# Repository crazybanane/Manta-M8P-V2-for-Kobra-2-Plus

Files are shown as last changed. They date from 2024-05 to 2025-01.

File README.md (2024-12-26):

THIS REPO IS UNDER CONSTRUCTION!!!!

UPDATE 26.12.2024

Hello,

here you can find the Printer.cfg for an Kobra 2 Plus in combination with an Manta M8P v2.0

At the moment there is only a tested Version that works for me!
Test at your own risk!!!
Updates follows.

Also you can get Print files to Print for your own New Housing for the Hardware, you find them in "Case Print Files". Please lookup with your connections and configuration. This is an early Version that is not 100% correct!

PLS advice that you can change PINs to your own likeness but then you have to edit the CFG!

| Part | Pinout Label | Manta M8P v2.0 | Pin / Pin Assignment |
|----|----|----|----|
| Probe / ABL Sensor | E-CON: LEVEL | Probe PD13 | If you use BlTouch: (PD13/Sensor) \[PD12/Servo) |
| Acceleration Sensor Printhead = X E-CON | E-CON: MOSI E-CON: MISO E-CON: SCLK E-CON: CS E-CON: 5V | SPI: SPI_MOSI SPI: SPI_MISO SPI: SPI_SCK SPI: SPI_CS SPI: 5V SPI_GND| PA7 PA6 PA5 PE10 (SPI: 5V) (SPI: GND)|
| Acceleration Sensor Bed = Y ACC-SENSOR | ACC-SENSOR: MOSI ACC-SENSOR: MISO ACC-SENSOR: SCLK ACC-SENSOR: CS ACC-SENSOR: 5V ACC-SENSOR: GND | SPI: SPI_MOSI SPI: SPI_MISO SPI: SPI_SCK RGB: PD15 SPI_5V: 5V SPI_GND: SPI_GND| PA7 PA6 PA5 PD15 (Motor: 5V) (Motor → GND -) |
| Printhead's 24V main | E-CON: 24V | Motor Fan → 24V + | (Motor Fan → 24V +) |
| Printhead's GND main | E-CON: GND | Motor Fan → 24V - | (Motor Fan → 24V -) |
| Part Cooling Fan | E-CON: F0 | FAN1 | FAN0 PF7 |
| Heatsink Cooling Fan | E-CON: F1 | FAN2 | FAN1 PF9 |
| Thermistor Hotend | E-CON: T0 | TH1 | PC1 |
| Cartridge Heater | E-CON: H+ / H- (3x) | HE0+ / HE0- | HE0 PA0 |
| Thermistor Bed | T1/GND | TB1 | PC0 |
| Heater Bed | HOTBED + / - | H-BED + / - | BED OUT PF5 |
| PE / Chassis GND | E-/X-CON: CHASSIS GND | PE-Wire PSU | (PE-Wire PSU) |
| Filament Runout Sensor | X-CON: FILAMENT/GND | MT_DET1 !PF2/GND | !PF2 M3-Stop |
| X Limit Switch | X-CON: X LIMIT/GND | X !PF4/GND | !PF4 M1-Stop |
| Y Limit Switch | Y-CON: LIMIT/GND | Y !PF3/GND | !PF3 M2-Stop |
| Mainboard Cooling Fan | MB-FAN + / - | FAN2 → 24V + / - | (FAN2 PF6 → 24V + / -) |
| Z-Offset Sensor | CALIBRATION S/GND | Z+ PD13/14/GND | ^PD13/14 |
| Extruder Motor | E-CON: A1/A2/B1/B2 | E0-MOTOR: 1A/1B/2A/2B | step: PB5 / dir: PB3 / enable: !PB6 / uart: PD5 |
| X-Axis Motor | X-CON: A1/A2/B1/B2 | X-MOTOR: 1A/1B/2A/2B | step: PE6 / dir: PE5 / enable: !PC14 / uart: PC13 |

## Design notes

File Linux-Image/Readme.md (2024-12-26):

Pre-Alpha State!!!!

Hello, 

i got a booting version for CB2 with newer kernel and "latest" (25.02) Armbian Version and kernel 6.12.

I dont take care if you use this Image, its under your own risk!

First Download CB2 image https://drive.google.com/file/d/1ZcWxQnl73ZC4QlOMRiY9tBDAFCI9ZEce/view?usp=sharing
Burn Image to SD-Card
Open SD-Card on your Computer goto directory "root" and search for file "not logged in yet"

Open the file and change it to your settings that you need (Wifi/password/User etc.)
Save the file and put the Card in the Printer.

Wait about 2-3 mins to boot, you should see with a programm of your choice that there will be an IP address to where you can connect via SSH.

First you have to log in with root/1234

wait until terminal is refreshed then logout and login via user biqu pass biqu and now you have to manually install Klipper via Kiauh.

* **Step 1:** \
To download this script, it is necessary to have git installed. If you don't have git already installed, or if you are unsure, run the following command:
```shell
sudo apt-get update && sudo apt-get install git -y
```

* **Step 2:** \
Once git is installed, use the following command to download KIAUH into your home-directory:

* **Step 3:** \
Finally, start KIAUH by running the next command:

* **Step 4:** \
You should now find yourself in the main menu of KIAUH. You will see several actions to choose from depending
on what you want to do. To choose an action, simply type the corresponding number into the "Perform action"
prompt and confirm by hitting ENTER.

After you installed the minimal Klipper functions you have to edit serial.rules

Open MC and search for 

Edit file 

and Copy Paste following text

```shell
# do not edit this file, it will be overwritten on update

ACTION=="remove", GOTO="serial_end"
SUBSYSTEM!="tty", GOTO="serial_end"

SUBSYSTEMS=="usb", IMPORT{builtin}="usb_id", IMPORT{builtin}="hwdb --subsystem=usb"
SUBSYSTEMS=="pci", ENV{ID_BUS}=="", ENV{ID_BUS}="pci", \
  ENV{ID_VENDOR_ID}="$attr{vendor}", ENV{ID_MODEL_ID}="$attr{device}", \
  IMPORT{builtin}="hwdb --subsystem=pci"

# /dev/serial/by-path/, /dev/serial/by-id/ for USB devices
KERNEL!="ttyUSB[0-9]*|ttyACM[0-9]*", GOTO="serial_end"

SUBSYSTEMS=="usb-serial", ENV{.ID_PORT}="$attr{port_number}"

IMPORT{builtin}="path_id"
ENV{ID_PATH}=="?*", ENV{.ID_PORT}=="", SYMLINK+="serial/by-path/$env{ID_PATH}"
ENV{ID_PATH}=="?*", ENV{.ID_PORT}=="?*", SYMLINK+="serial/by-path/$env{ID_PATH}-port$env{.ID_PORT}"

IMPORT{builtin}="usb_id"
ENV{ID_SERIAL}=="", GOTO="serial_end"
SUBSYSTEMS=="usb", ENV{ID_USB_INTERFACE_NUM}="$attr{bInterfaceNumber}"
ENV{ID_USB_INTERFACE_NUM}=="", GOTO="serial_end"
ENV{.ID_PORT}=="", SYMLINK+="serial/by-id/$env{ID_BUS}-$env{ID_SERIAL}-if$env{ID_USB_INTERFACE_NUM}"
ENV{.ID_PORT}=="?*", SYMLINK+="serial/by-id/$env{ID_BUS}-$env{ID_SERIAL}-if$env{ID_USB_INTERFACE_NUM}-port$env{.ID_PORT}"

LABEL="serial_end"

```

save file.

Now reboot CB2

In terminal type

put in editor

```shell
allow-hotplug can0
iface can0 can static
        bitrate 1000000
        up ip link set can0 txqueuelen 1024
```

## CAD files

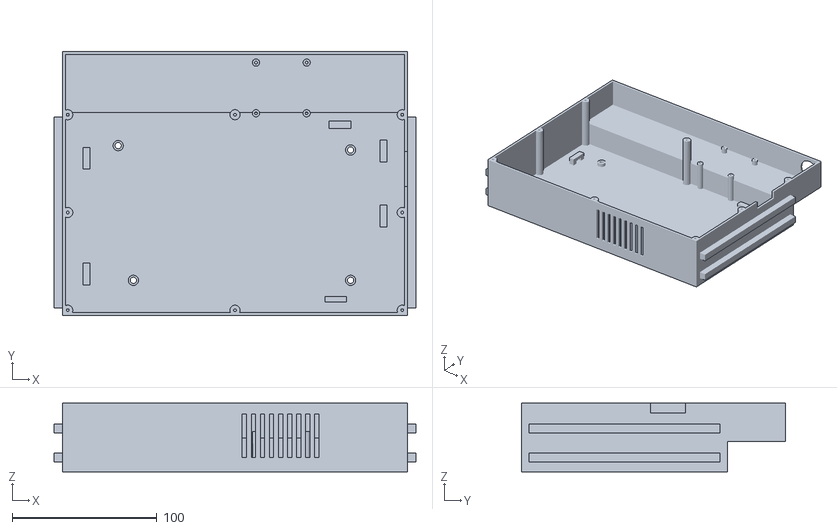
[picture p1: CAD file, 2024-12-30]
Case Print Files/Kobra 2Plus HW-Case M3.stl
250.0 x 182.0 x 47.5

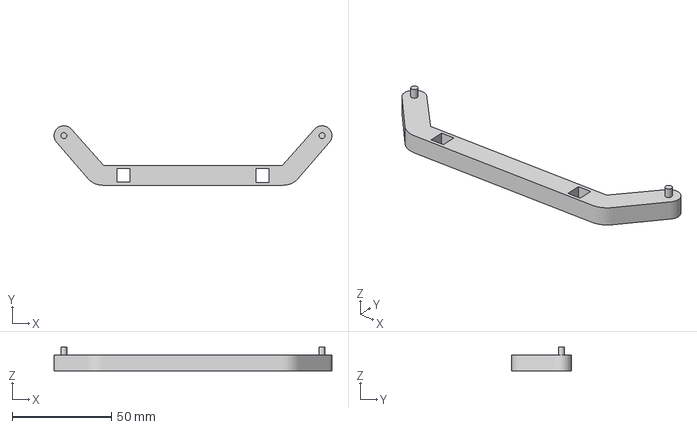
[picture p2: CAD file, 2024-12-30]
Printable Upgrades/halter rolle.3mf
140.0 x 30.0 x 12.0 mm

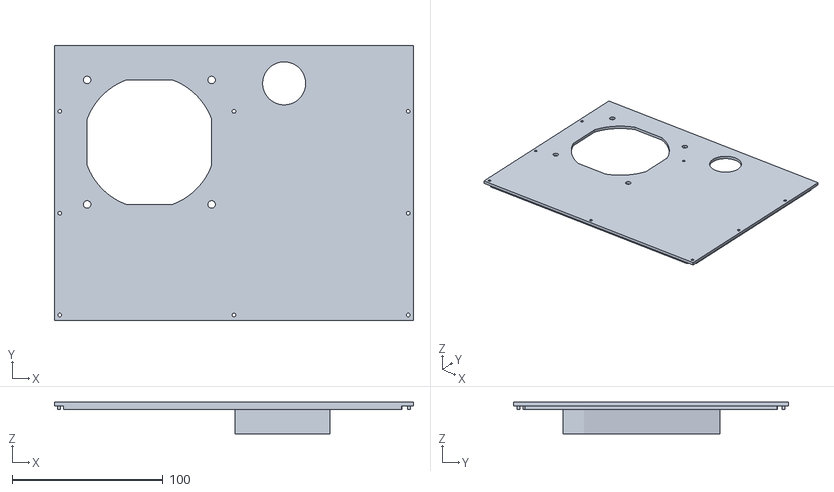
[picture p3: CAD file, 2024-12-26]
Case Print Files/Kobra 2 Plus Case HW-Lid.stl
238.0 x 182.0 x 21.2

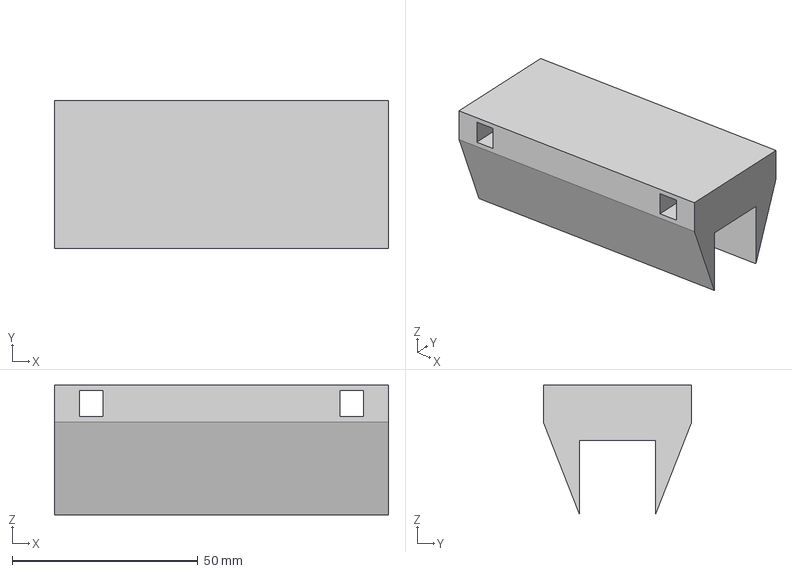
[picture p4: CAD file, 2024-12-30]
Printable Upgrades/halter rolle oben.3mf
90.0 x 40.0 x 35.0 mm

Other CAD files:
Case Print Files/Kobra 2 Plus HW-Case Melt Studs.stl

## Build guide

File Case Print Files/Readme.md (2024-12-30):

Hello here you can find an Case for Kobra 2 Plus to printyourself.
The Cases are made ONLY for Manta M8P V2 Board.
There i use 2 different FANs.
The 4020 Blower Fan is for cooling the Motor-Drivers
The 82mm Fan is for cooling CB2
You can choose between 2 Layouts

- Case with melt points to hold Board "Forever" 
- Case with holes to melt in Brass M3 nuts "Detachable" MoBo
- Lid is not tested yet !!!

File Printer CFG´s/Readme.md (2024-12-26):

Here you find the "printer.cfg"s for Kobra 2 Plus.

The Backup of the original Printer Hardware you find under K2PLUS-Orig-printer.cfg.

The Edited Version for Manta M8P V2 Board you find under K2PLUS-M8PV2-printer.cfg

When you use the CFGs dont forget to Change names to printer.cfg before you Upload to Klipper.

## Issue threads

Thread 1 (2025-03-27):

case files

dash3811, 2025-03-27:
can you proide the case files so taht we can edit them in fusion or some other software? They are too big for me to print and i need to edit them.

Closed 2025-04-21.

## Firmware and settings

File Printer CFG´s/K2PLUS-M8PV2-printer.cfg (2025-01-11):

# This file contains common pin mappings for the BIGTREETECH Manta M8P V2.0 for an Anycubic Kobra 2 Plus Printer
# To use this config, the firmware should be compiled for the
# STM32H723 with a "128KiB bootloader" "25 MHz crystal"
# and "USB (on PA11/PA12)", "CAN bus (on PD0/PD1)" or Serial (on USART1 PA10/PA9).
[include mainsail.cfg]

# Motor1
[stepper_x]
step_pin: PE6
dir_pin: PE5
enable_pin: !PC14
microsteps: 16
rotation_distance: 31.85
endstop_pin: ^!PF4
position_endstop: -8.0
position_max : 330.0
position_min : -9.0
homing_speed : 100.000000
second_homing_speed : 15.000000
homing_retract_dist : 10

# Motor2
[stepper_y]
step_pin: PE2
dir_pin: PE1
enable_pin: !PE4
microsteps: 16
rotation_distance: 31.76
endstop_pin: ^!PF3
position_endstop : -5.000000
position_max : 330.000000
position_min : -5
homing_speed : 100.000000
second_homing_speed : 15.000000
homing_retract_dist : 10


# Motor3
[stepper_z]
step_pin: PB8
dir_pin: PB7
enable_pin: !PE0
microsteps: 16
rotation_distance: 7.98
#endstop_pin: ^PF2
#position_endstop : 1.080000
endstop_pin: probe:z_virtual_endstop
position_max : 401.000000
position_min : -5
homing_speed : 32.000000
homing_retract_dist : 8
second_homing_speed : 4.000000

# Motor4
# The M8P only has 4 heater outputs which leaves an extra stepper
# This can be used for a second Z stepper, dual_carriage, extruder co-stepper,
# or other accesory such as an MMU
[extruder]
step_pin: PB4
dir_pin: PB3
enable_pin: !PB6
heater_pin: PA0 # HE0
sensor_pin: PB0 # T0
microsteps : 16
rotation_distance: 6.7
nozzle_diameter : 0.600000
filament_diameter : 1.750000
max_extrude_cross_section: 20
sensor_type : EPCOS 100K B57560G104F
#control : pid
#pid_Kp : 12.723368
#pid_Ki : 0.489360
#pid_Kd : 82.701890
min_temp : -273.15
max_temp : 275
pressure_advance : 0.033600

# Motor5
#[extruder]
#step_pin: PG13
#dir_pin: PG12
#enable_pin: !PG15
#microsteps: 16
#rotation_distance: 33.500
#nozzle_diameter: 0.4
#filament_diameter: 1.75
#heater_pin: PA0 # HE0
#sensor_pin: PB0 # T0
#sensor_type: Generic 3950
#control: pid
#pid_Kp: 22.2
#pid_Ki: 1.08
#pid_Kd: 114
#min_temp: 0
#max_temp: 250

## End-Stop 5
#[filament_switch_sensor material_0]
#switch_pin: PF0

## Motor6
#[extruder1]
#step_pin: PG9
#dir_pin: PD7
#enable_pin: !PG11 
#heater_pin: PA1 # HE1 
#sensor_pin: PC5 # T1
#...

## End-Stop 6
#[filament_switch_sensor material_1]
#switch_pin: PC15

## Motor7
#[extruder2]
#step_pin: PD4
#dir_pin: PD3
#enable_pin: !PD6
#heater_pin: PA3 # HE2
#sensor_pin: PC4 # T2
#...

## Motor8
#[extruder3]
#step_pin: PC7
#dir_pin: PC8
#enable_pin: !PD2
#heater_pin: PA5 # HE3
#sensor_pin: PA7 # T3
#...

[heater_bed]
heater_pin: PF5
sensor_pin: PB1 # TB 
sensor_type: ATC Semitec 104GT-2
control: pid
pid_Kp : 70.769227
pid_Ki : 1.134122
pid_Kd : 1103.999942
min_temp: 0
max_temp: 105

#[fan_generic soc-fan]
#pin: host:gpio79  #CB1
#pin: host:gpio26  #CM4

# Fan0
[fan]
pin: PF9
kick_start_time: 0.5
off_below: 0.10
max_power: 1.0
# Fan1
[heater_fan hotend_cooling_fan]
pin: PF7
kick_start_time: 0.5
heater_temp : 50
fan_speed : 1
off_below: 0.10
## Fan2
[fan_generic board_cooling_fan]
pin: PA2
tachometer_pin: PC1
#pin : PF6
#stepper : stepper_x,stepper_y,stepper_z,extruder
max_power : 1.0
#idle_timeout : 30
#heater : extruder,heater_bed


## Fan3
#[heater_fan fan3]
#pin: PF8

## Fan4
#[heater_fan fan4]
#pin: PA4

## Fan5
#[heater_fan fan5]
#pin: PA6
#tachometer_pin: PC2

# Fan6
#[heater_fan fan6]
#pin: PA2
#tachometer_pin: PC1
#fan_speed : 1
#max_power: 1.0

[mcu]
canbus_uuid: 9c85f75f7f1b

[input_shaper]
shaper_type_x : mzv
shaper_freq_x : 54.800000

[resonance_tester]
probe_points : 165,165,50
accel_chip : lis2dw
min_freq : 1.000000
max_freq : 150.000000
accel_per_hz : 150.000000
hz_per_sec : 1.000000
max_smoothing : 0.500000

[lis2dw]
cs_pin: PA15
spi_bus: spi3a
#spi_software_sclk_pin: PC10
#spi_software_mosi_pin: PC12
#spi_software_miso_pin: PC11
#spi_speed : 1000000
axes_map : x,y,z

[temperature_sensor CB2]
sensor_type: temperature_host
min_temp: 10
max_temp: 100

[printer]
kinematics: cartesian
max_velocity: 300
max_accel: 3000
max_z_velocity: 16
max_z_accel: 3000
square_corner_velocity : 15.000000

########################################
# TMC2209 configuration
########################################

# Motor1
[tmc2209 stepper_x]
uart_pin: PC13
#diag_pin: PF4 
interpolate : 1
sense_resistor : 0.110
driver_sgthrs : 100
run_current : 1.4
hold_current : 0.7
stealthchop_threshold : 99999


# Motor2
[tmc2209 stepper_y]
uart_pin: PE3
#diag_pin: PF3
interpolate : 1
run_current : 1.7
hold_current : 0.9
sense_resistor : 0.110
driver_sgthrs : 100
stealthchop_threshold: 99999

## Motor3
[tmc2209 stepper_z]
uart_pin: PB9
#diag_pin: PF2
interpolate : 1
run_current : 1.5
hold_current : 1.0
sense_resistor : 0.110
driver_sgthrs : 100
stealthchop_threshold : 99999

# Motor4
[tmc2209 extruder]
uart_pin: PB5
#diag_pin: PF1
interpolate : 1
run_current : 0.8
hold_current : 0.4
sense_resistor : 0.110
driver_sgthrs : 10
stealthchop_threshold : 0


[board_pins]
aliases:
    # EXP1 header
    EXP1_1=PE7, EXP1_2=PG1,
    EXP1_3=PG0, EXP1_4=PF15,
    EXP1_5=PF14, EXP1_6=PF13,    # Slot in the socket on this side
    EXP1_7=PF12, EXP1_8=PF11,
    EXP1_9=<GND>, EXP1_10=<5V>,

    # EXP2 header
    EXP2_1=PE13, EXP2_2=PE12,
    EXP2_3=PE15, EXP2_4=PE11,
    EXP2_5=PE10, EXP2_6=PE14,      # Slot in the socket on this side
    EXP2_7=PE8, EXP2_8=<RST>,
    EXP2_9=<GND>, EXP2_10=<NC>

# See the sample-lcd.cfg file for definitions of common LCD displays.

#[auto_leveling]
#target_spot_x : 64.600000
#target_spot_y : 339.600000

#[probe]
#z_offset : 0.39300
#pin : z_virtual_endstop #PD8
#deactivate_on_each_sample : True
#x_offset : 0.0
#y_offset : 0.0
#z_offset : -1.080000
#speed : 4.0
#lift_speed : 8.0
#samples : 2
#sample_retract_dist : 2.0
#samples_result : average
#samples_tolerance : 0.1
#samples_tolerance_retries : 2
#move_after_each_sample : -2.0
#z_offset_adjust : 0.2



[bltouch]
sensor_pin: PD13
control_pin: PD12
#z_offset: 0.100
y_offset: 14
x_offset: 28

probe_with_touch_mode: true

[safe_z_home]
home_xy_position: 40, 280
speed: 150
z_hop: 15
z_hop_speed: 8

[bed_mesh]
speed: 200
horizontal_move_z: 8
mesh_min: 19, 19
mesh_max: 305, 310
mesh_pps: 3, 3
probe_count: 8, 8
algorithm: bicubic
## Proximity switch
#[probe]
#pin: PD8

#[output_pin ps_on_pin]
#pin: PD14

#[neopixel my_neopixel_1]
#pin: PD15

#[hall_filament_width_sensor]
#adc1: PC0
#adc2: PF10
[include moonraker_obico_macros.cfg]
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

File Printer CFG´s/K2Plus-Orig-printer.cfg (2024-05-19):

[printer]
kinematics : cartesian
max_velocity : 500.000000
max_accel : 10000.000000
max_z_velocity : 16.000000
max_z_accel : 3000.000000
minimum_z_position : -20.000000
square_corner_velocity : 15.000000
[stepper_x]
step_pin : PE1
dir_pin : PE0
enable_pin : !PE14
endstop_pin : !PE8
microsteps : 16
full_steps_per_rotation : 200
step_distance : 0.00997
position_endstop : -5.000000
position_max : 330.000000
position_min : -5
homing_speed : 60.000000
second_homing_speed : 15.000000
homing_retract_dist : 10
virtrual_endstop : 0
[stepper_y]
step_pin : PG11
dir_pin : !PE11
enable_pin : !PG8
endstop_pin : !PE13
microsteps : 16
full_steps_per_rotation : 200
step_distance : 0.00997
position_endstop : -5.000000
position_max : 330.000000
position_min : -5
homing_speed : 60.000000
second_homing_speed : 15.000000
homing_retract_dist : 10
virtrual_endstop : 0
[stepper_z]
step_pin : PG15
dir_pin : !PG14
enable_pin : !PG18
endstop_pin : PG9
microsteps : 16
full_steps_per_rotation : 200
step_distance : 0.002499
position_endstop : 1.080000
position_max : 401.000000
position_min : -5
homing_speed : 32.000000
homing_retract_dist : 8
second_homing_speed : 4.000000
virtrual_endstop : 0
[extruder]
step_pin : PC1
dir_pin : PC0
enable_pin : !PG7
heater_pin : PG12
sensor_pin : PB13
microsteps : 16.000000
full_steps_per_rotation : 200
step_distance : 0.00197
nozzle_diameter : 0.400000
filament_diameter : 1.750000
sensor_type : EPCOS 100K B57560G104F
control : pid
pid_Kp : 12.723368
pid_Ki : 0.489360
pid_Kd : 82.701890
min_temp : -200
max_temp : 275
pressure_advance : 0.030000
[flow_calibration]
start_x : 20
start_y : 20
line_length : 150.000000
line_space : 5.000000
step_distance : 0.01
[tmc2209 stepper_x]
tx_pin : PE4
uart_pin : PE5
uart_address : 0
interpolate : 1
sense_resistor : 0.075
microsteps : 16
driver_sgthrs : 100
run_current : 1.4
hold_current : 0.7
stealthchop_threshold : 0
[tmc2209 stepper_y]
tx_pin : PE4
uart_pin : PE5
interpolate : 1
run_current : 1.8
hold_current : 1.0
uart_address : 3
sense_resistor : 0.075
microsteps : 16
driver_sgthrs : 105
stealthchop_threshold : 0
[tmc2209 stepper_z]
tx_pin : PE4
uart_pin : PE5
interpolate : 1
run_current : 1.8
hold_current : 1.0
uart_address : 1
sense_resistor : 0.075
microsteps : 16
driver_sgthrs : 100
stealthchop_threshold : 99999
[tmc2209 extruder]
tx_pin : PE4
uart_pin : PE5
interpolate : 1
run_current : 0.8
hold_current : 0.4
uart_address : 2
sense_resistor : 0.075
microsteps : 16
driver_sgthrs : 10
stealthchop_threshold : 99999
[heater_bed]
heater_pin : PG17
sensor_pin : PB14
sensor_type : ATC Semitec 104GT-2
control : pid
pid_Kp : 70.769227
pid_Ki : 1.134122
pid_Kd : 1103.999942
min_temp : -200
max_temp : 105
[verify_heater extruder]
max_error : 120
check_gain_time : 20
hysteresis : 5
heating_gain : 1
[verify_heater heater_bed]
max_error : 120
check_gain_time : 180
hysteresis : 5
heating_gain : 1
[fan]
pin : PG13
[heater_fan hotend_cooling_fan]
pin : PG6
heater_temp : 50
fan_speed : 1
[controller_fan board_cooling_fan]
pin : PG10
stepper : stepper_x,stepper_y,stepper_z,extruder
fan_speed : 1
idle_speed : 0
idle_timeout : 30
heater : extruder,heater_bed
[gcode_arcs]
[pause_resume]
[mcu]
mem_interface : mem_interface_DSP
[input_shaper]
shaper_type_x : mzv
shaper_freq_x : 54.800000
shaper_type_y : 3hump_ei
shaper_freq_y : 63.800000
[resonance_tester]
probe_points : 165,165,50
accel_chip_x : adxl345 X
accel_chip_y : adxl345 Y
min_freq : 1.000000
max_freq : 140.000000
accel_per_hz : 150.000000
hz_per_sec : 1.000000
max_smoothing : 0.000000
[adxl345 X]
spi_speed : 1000000
spi_bus : spi1
adxl_type : lis2dw12
axes_map : x,y,z
rate : 1600
[adxl345 Y]
spi_speed : 1000000
spi_bus : spi0
adxl_type : lis2dw12
axes_map : x,y,z
rate : 1600
[bed_mesh]
speed : 60.0
horizontal_move_z : 5.0
mesh_min : 19,19
mesh_max : 305,310
probe_count : 7,7
mesh_pps : 3,3
algorithm : lagrange
[auto_leveling]
bed_mesh_temp : 60.0
extruder_temp : 210.0
extruder_wipe_z : -2.3
move_speed : 30.0
extrude_x : 66
extrude_y : 0
extrude_z : 15
extrude_length : 80.0
extrude_speed : 3.0
extruder_pullback_length : 25.0
extruder_pullback_speed : 30.0
extruder_cool_down_temp : 140.0
lifting_after_completion : 15.0
[safe_z_home]
home_x_position : 40.00000
home_y_position : 280.00000
speed : 150.0
z_lift : 10
z_hop : 15.0
z_hop_speed : 8.0
[probe]
pin : PB8
deactivate_on_each_sample : True
x_offset : 0.0
y_offset : 0.0
z_offset : -1.080000
speed : 4.0
final_speed : 4.0
lift_speed : 8.0
samples : 2
sample_retract_dist : 2.0
samples_result : weighted
samples_tolerance : 0.1
samples_tolerance_retries : 2
move_after_each_sample : -2.0
z_offset_adjust : 0.2
[auto_leveling]
target_spot_x : 64.600000
target_spot_y : 339.600000
[probe]
z_offset_adjust : 0.39300
[bed_mesh_probe]
pin : PG9
deactivate_on_each_sample : True
x_offset : 24.0
y_offset : 13.35
speed : 4.0
final_speed : 4.0
lift_speed : 8.0
samples : 2
sample_retract_dist : 5.0
samples_result : weighted
samples_tolerance : 0.1
samples_tolerance_retries : 2
[system]
language : 1
boot : 1
wifi : 1
area : 0
run_mode : 1
sound : 0
material_breakage_detection : 0
extrude_speed : 300
retract_speed : 300
retract_extrude_length : 6
screen_off_time : 999
material_breakage_retries : 2
material_breakage_interval : 3
device_model : Anycubic kobra 2 Plus
print_size : 320*320*400mm
device_cfg_version : 0.0.0
[pid_calibrate]
test_points : 100,100,5
extruder_target_temp : 230
heater_bed_target_temp : 60
[besh_profile_default]
version : 1
points : -0.692500, -0.562500, -0.551000, -0.581000, -0.629000, -0.780000, -1.010000, -0.486500, -0.432500, -0.490000, -0.487500, -0.515500, -0.599000, -0.710000, -0.282500, -0.319000, -0.403000, -0.429000, -0.420000, -0.464000, -0.478500, -0.141500, -0.227500, -0.362500, -0.365000, -0.358500, -0.371500, -0.347500, -0.005000, -0.121000, -0.240000, -0.296000, -0.281500, -0.278500, -0.212500, 0.091000, -0.021500, -0.166500, -0.211500, -0.225500, -0.234000, -0.185000, 0.059000, -0.042500, -0.140000, -0.200000, -0.208500, -0.241500, -0.213500
mesh_max : 305.000000, 310.000000
mesh_min : 19.000000, 19.000000
algo : lagrange
max_x : 304.960000
min_x : 19.000000
max_y : 310.000000
min_y : 19.000000
mesh_x_pps : 3
mesh_y_pps : 3
x_count : 7
y_count : 7

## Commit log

2024-05-16 Update generic-bigtreetech-manta-m8p-V2_0.cfg
    First version untested
    [generic-bigtreetech-manta-m8p-V2_0.cfg]
2024-05-17 Update Manta M8P v2 for Kobra 2 Plus
    1st Version without errors! No Printing or printer functions tested.
2024-05-17 Add files via upload
    Housing for Board to change Part 1 V0.1
    [Kobra 2 Plus Body Tech 1.stl]
2024-05-18 Add files via upload
    Kobra Housing Front Part 1 for BTT Manta M8P v2 without connectors (Wifi- Only)
2024-05-18 Rename kobra 2 housing wo Conn.stl to Print Files /kobra 2 housing w\o Conn.stl
    [kobra 2 housing w\o Conn.stl]
2024-05-18 Rename Kobra 2 Plus Original to Kobra 2 Plus Original cfg /printer.cfg
    [printer.cfg]
2024-05-18 Rename Manta M8P v2 for Kobra 2 Plus to Manta M8P v2 for Kobra 2 Plus cfg/printer.cfg
    [printer.cfg]
2024-05-18 Rename printer.cfg to Kobra 2 Plus Original_printer.cfg
    [Kobra 2 Plus Original_printer.cfg]
2024-05-18 Rename printer.cfg to Manta M8P v2 for Kobra 2 Plus_printer.cfg
    [Manta M8P v2 for Kobra 2 Plus_printer.cfg]
2024-05-18 Rename Kobra 2 Plus Original_printer.cfg to Kobra 2 Plus Original_printer.cfg
    [Kobra 2 Plus Original_printer.cfg]
2024-05-19 Update Kobra 2 Plus Original_printer.cfg
    [Kobra 2 Plus Original_printer.cfg]
2024-05-20 Update Manta M8P v2 for Kobra 2 Plus_printer.cfg
    [Manta M8P v2 for Kobra 2 Plus_printer.cfg]
2024-11-21 Update Manta M8P v2 for Kobra 2 Plus_printer.cfg
    Actually the printer works with this version. In this CFG there is only Z-Probe via BL-touch activated.
    There will be more changes in the future
    [Manta M8P v2 for Kobra 2 Plus_printer.cfg]
2024-12-26 Create Readme.md
    Rebuild the whole Design of the Case for the Hardware
2024-12-26 Add files via upload
    This is the Melting Stud Design
    [Kobra 2 Plus HW-Case.stl]
2024-12-26 Rename Kobra 2 Plus HW-Case.stl to Kobra 2 Plus HW-Case Melt Studs.stl
    [Kobra 2 Plus HW-Case Melt Studs.stl]
2024-12-26 Add files via upload
    Add LID
    [Kobra 2 Plus Case HW-Lid.stl]
2024-12-26 Rename Kobra 2 Plus Original_printer.cfg to K2Plus-Org-printer.cfg
    [K2Plus-Org-printer.cfg]
2025-01-11 Update K2PLUS-M8PV2-printer.cfg
    added LIS2DW sensor and tested bed sensor ok. Not final.
    [K2PLUS-M8PV2-printer.cfg]
